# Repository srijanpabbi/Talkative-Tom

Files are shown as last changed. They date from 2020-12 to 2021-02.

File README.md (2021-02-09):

# Talkative-Tom
GOTO: https://srijanpabbi.in/projects/#topic_tt
Doc: https://srijanpabbi.blogspot.com/2020/01/talkative-tom.html
Audio storing &amp; playback device with pitch modification using MSP-430 TI-microcontroller / Atmega328P microcontroller, SPI Serial Flash for Storage &amp; class-D amplifier for speaker

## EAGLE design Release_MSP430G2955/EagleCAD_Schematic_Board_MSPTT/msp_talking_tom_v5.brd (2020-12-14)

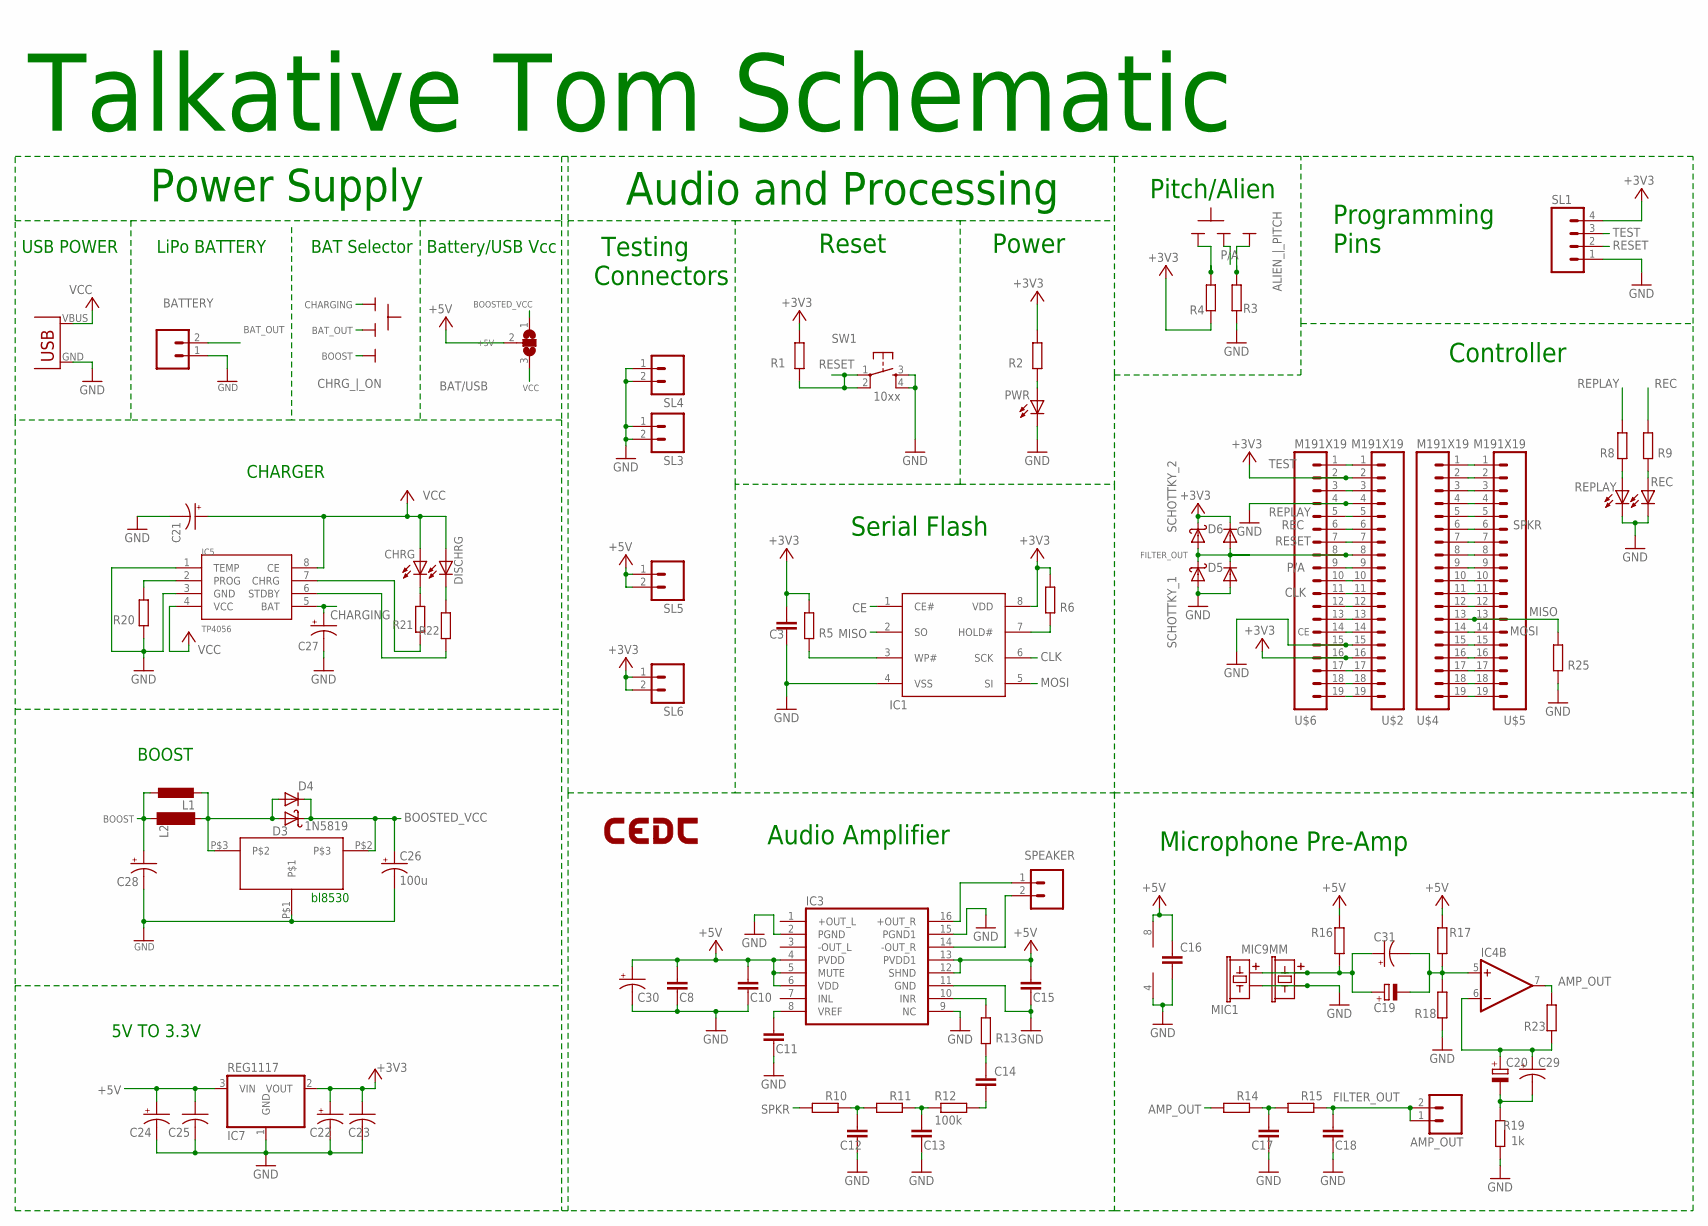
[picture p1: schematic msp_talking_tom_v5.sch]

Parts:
ALIEN_|_PITCH: SLIDESWITCH-BIG; BIGSWITCH
AMP_OUT: M02; 02P
BAT/USB: SJ2W; SJ_2
BATTERY: M02JST-PTH-2; 02P
C3, C12, C16, C17, C18, C23, C25: 0.1u; C0805
C8, C10, C15: 1uf; C1206
C11: 0.1uf; C1206
C13: 0.1uf; C0805
C14: 0.47uF; C0603
C19, C20: 10u; E2,5-5
C21, C22, C24, C27, C28, C29, C31: 10u; C/6032-28R
C26: 100u; C/6032-28R
C30: CAP_POL_10V; C/6032-28R
CHRG: LED3MM
CHRG_|_ON: SLIDESWITCH-BIG; BIGSWITCH
D3: 1N5819; DO41-10
D4, D5, D6: DIODE_DIODE-DO214AC; DIODE_DO214AC
DISCHRG: LED3MM
IC1: SST25VF040B_SPI_FLASH; SOIC08
IC3: PAM8403; SOP-16
IC4: LM358N; DIL08
IC5: TP4056; SOP-8
IC6: BL8530_5V
IC7: REG1117; SOT223
L1: L-EUL5650M; L5650M
L2: 47uH; MS85
LOGO2: LOGO-CEDTSILK-18MM; LOGO-CEDT-SILK-18MM
MIC1: MICMIC-4.5MM; MIC-4.5MM
MIC9MM: MIC9.7MM; MIC-9.7MM
PWR: LED3MM
R1, R3, R4, R5, R6, R13, R18, R25: 10k; 0204/7
R2, R8, R9, R19: 1k; 0204/7
R10, R11, R14, R15: 330; 0204/7
R12: 100k; 0204/7
R16: 4.7k; 0204/7
R17, R23: 20k; 0204/7
R20: R-EU_0204/7; 0204/7
R21, R22: 470; 0204/7
REC: LED3MM
REPLAY: LED3MM
SCHOTTKY_1, SCHOTTKY_2: 1N5819; DO41-10
SL1: M04; 04P
SL3, SL4, SL5, SL6: M02; 02P
SPEAKER: M02JST-PTH-VERT; 02P
SW1: 10xx; B3F-10XX
U$1: USB(POWER)
U$2, U$4, U$5, U$6: M191X19; 1X19

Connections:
+3V3: C3.1, C22.+, C23.1, D6.C, IC1.8 (VDD), IC7.2 (VOUT), R1.2, R2.2, R4.2, R5.1, R6.2, SCHOTTKY_2.C, SL1.4, SL6.1, SL6.2, U$2.2, U$2.16, U$6.2, U$6.16
+5V: BAT/USB.2, C8.1, C10.2, C15.2, C16.1, C24.+, C25.1, C30.+, IC3.4 (PVDD), IC3.5 (MUTE), IC3.6 (VDD), IC3.12 (SHND), IC3.13 (PVDD1), IC4.8 (V+), IC7.3 (VIN), R16.2, R17.2, SL5.1, SL5.2
AMP_OUT: IC4.7 (OUT), R14.1, R23.2
AVCC: U$4.16, U$5.16
BAT_OUT: BATTERY.2, CHRG_|_ON.2
BOOST: C28.+, CHRG_|_ON.3, L1.1, L2.1
BOOSTED_VCC: BAT/USB.1, C26.+, D3.C, D4.C, IC6.P$2
CE: IC1.1 (CE#), U$2.14, U$6.14
CHARGING: C27.+, CHRG_|_ON.1, IC5.5 (BAT)
CLK: IC1.6 (SCK), U$2.11, U$6.11
DVCC: U$4.2, U$5.2
FILTER_OUT: AMP_OUT.1, AMP_OUT.2, C18.1, D5.C, D6.A, R15.2, SCHOTTKY_1.C, SCHOTTKY_2.A, U$2.8, U$6.8
GND: BATTERY.1, C3.2, C8.2, C10.1, C11.2, C12.2, C13.2, C15.1, C16.2, C17.2, C18.2, C21.-, C22.-, C23.2, C24.-, C25.2, C26.-, C27.-, C28.-, C30.-, D5.A, IC1.4 (VSS), IC3.2 (PGND), IC3.9 (NC), IC3.11 (GND), IC3.15 (PGND1), IC4.4 (V-), IC5.1 (TEMP), IC5.3 (GND), IC6.P$1, IC7.1 (GND), MIC1.+ (2), MIC9MM.2, PWR.K (C), R3.2, R18.1, R19.1, R20.1, R25.1, REC.K (C), REPLAY.K (C), SCHOTTKY_1.A, SL1.1, SL3.1, SL3.2, SL4.1, SL4.2, SW1.3 (S), SW1.4 (S1), U$1.GND, U$2.4, U$2.15, U$6.4, U$6.15
MICIN1: C13.1, R11.2, R12.1
MISO: IC1.2 (SO), R25.2, U$4.13, U$5.13
MOSI: IC1.5 (SI), U$4.14, U$5.14
unnamed: U$2.3, U$6.3
unnamed: IC1.7 (HOLD#), R6.1
unnamed: IC1.3 (WP#), R5.2
unnamed: U$4.1, U$5.1
unnamed: U$4.15, U$5.15
unnamed: ALIEN_|_PITCH.3, R3.1
unnamed: U$4.4, U$5.4
unnamed: IC3.16 (+OUT_R), SPEAKER.1
unnamed: IC3.14 (-OUT_R), SPEAKER.2
unnamed: C14.2, R13.2
unnamed: IC3.10 (INR), R13.1
unnamed: C12.1, R10.2, R11.1
unnamed: PWR.A, R2.1
unnamed: C17.1, R14.2, R15.1
unnamed: IC5.2 (PROG), R20.2
unnamed: IC5.7 (CHRG), R21.1
unnamed: C14.1, R12.2
unnamed: R8.1, REPLAY.A
unnamed: C11.1, IC3.8 (VREF)
unnamed: ALIEN_|_PITCH.1, R4.1
unnamed: IC5.6 (STDBY), R22.1
unnamed: CHRG.K (C), R21.2
unnamed: DISCHRG.K (C), R22.2
unnamed: D3.A, D4.A, IC6.P$3, L1.2, L2.2
unnamed: C19.+, C31.+, MIC1.- (1), MIC9MM.1, R16.1
unnamed: C19.-, C31.-, IC4.5 (+IN), R17.1, R18.2
unnamed: C20.+, C29.+, IC4.6 (-IN), R23.1
unnamed: R9.2, REC.A
unnamed: U$2.19, U$6.19
unnamed: C20.-, C29.-, R19.2
unnamed: U$2.18, U$6.18
unnamed: U$2.17, U$6.17
unnamed: U$2.13, U$6.13
unnamed: U$2.12, U$6.12
unnamed: U$2.10, U$6.10
unnamed: U$4.3, U$5.3
unnamed: U$4.5, U$5.5
unnamed: U$4.7, U$5.7
unnamed: U$4.8, U$5.8
unnamed: U$4.9, U$5.9
unnamed: U$4.10, U$5.10
unnamed: U$4.11, U$5.11
unnamed: U$4.12, U$5.12
unnamed: U$4.17, U$5.17
unnamed: U$4.18, U$5.18
unnamed: U$4.19, U$5.19
P/A: ALIEN_|_PITCH.2, U$2.9, U$6.9
REC: R9.1, U$2.6, U$6.6
REPLAY: R8.2, U$2.5, U$6.5
RESET: R1.1, SL1.2, SW1.1, SW1.2 (P1), U$2.7, U$6.7
SPKR: R10.1, U$4.6, U$5.6
TEST: SL1.3, U$2.1, U$6.1
VCC: BAT/USB.3, C21.+, CHRG.A, DISCHRG.A, IC5.4 (VCC), IC5.8 (CE), U$1.VBUS (VCC)

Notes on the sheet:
Microphone Pre-Amp
Serial Flash
Reset
Testing Connectors
Controller
Audio Amplifier
Power
Programming Pins
Pitch/Alien
CHARGER
BOOST
5V TO 3.3V
bl8530
USB POWER
LiPo BATTERY
BAT Selector
Battery/USB Vcc
Power Supply
Audio and Processing
Talkative Tom Schematic

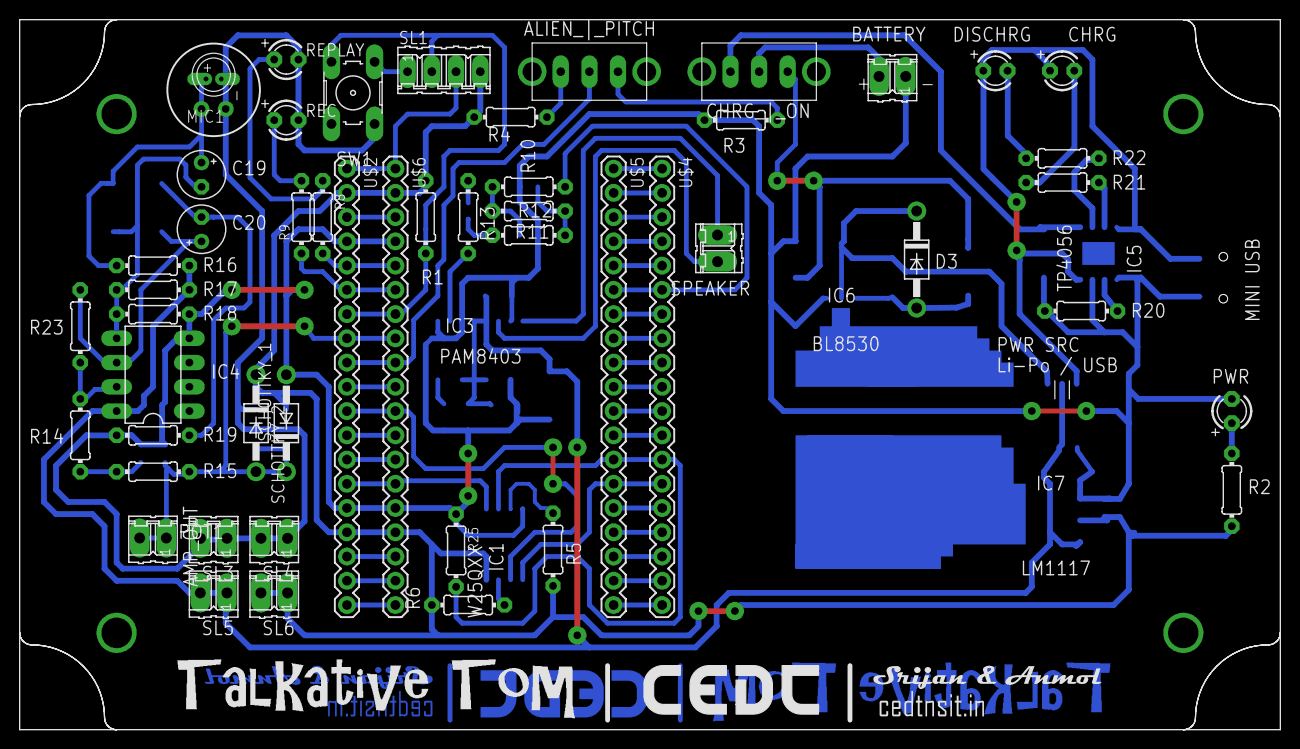
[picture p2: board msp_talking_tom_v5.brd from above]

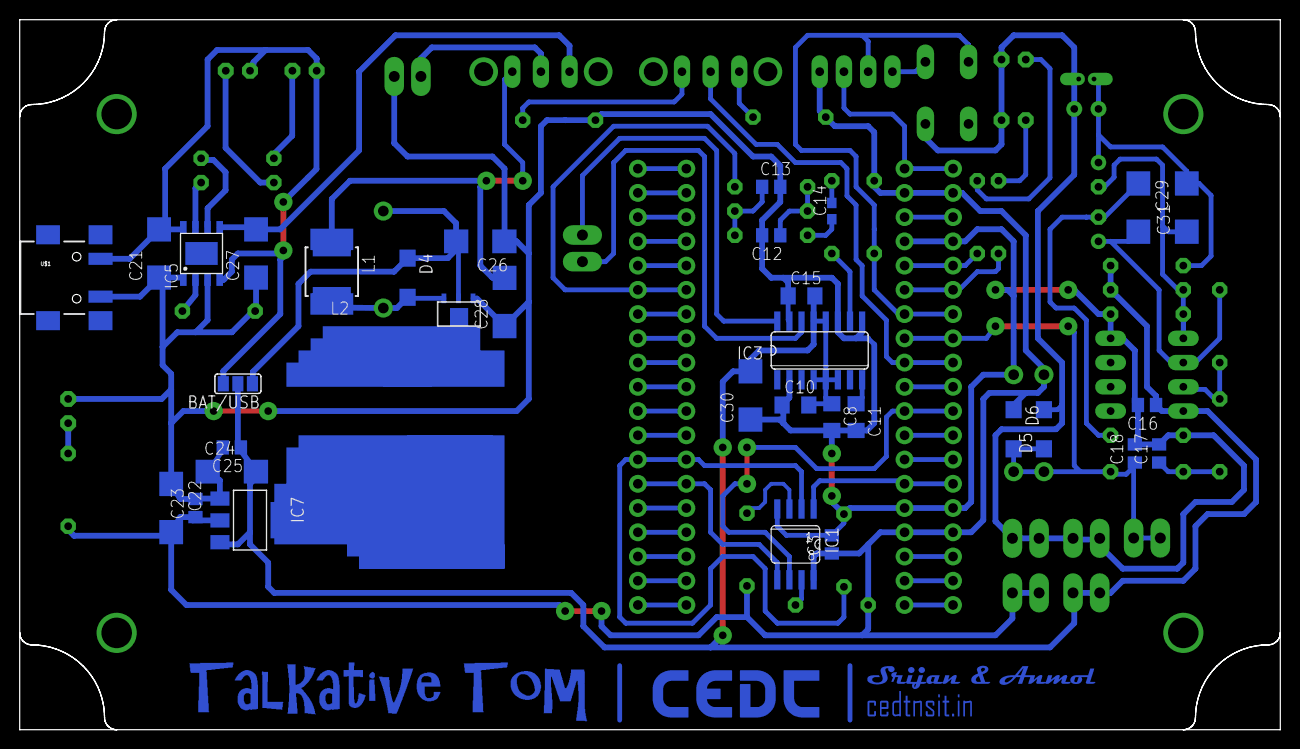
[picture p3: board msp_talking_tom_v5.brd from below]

Board: 2 copper layers, 132.1 x 74.4 mm, 86 parts (34 on the bottom side), 69 nets.

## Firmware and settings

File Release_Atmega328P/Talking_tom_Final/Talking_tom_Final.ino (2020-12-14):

#define WRITE_ENABLE       0x06
#define WRITE_DISABLE      0x04
#define CHIP_ERASE         0xc7
#define READ_STATUS_REG_1  0x05
#define READ_DATA          0x03
#define PAGE_PROGRAM       0x02
#define JEDEC_ID           0x9F
#define BLOCK_ERASE        0xD8

byte buf0[256];
byte buf1[256];
boolean enable_buf0 = true;
boolean enable_buf1 = false;
boolean write_pointer = true;
boolean read_pointer = true;
unsigned int bufByteCount = 0;
unsigned int buffByteCount = 0;
boolean flag = true;
int pagenumber = 0, recpage = 0;
uint8_t val = 0;
float current_ip = 0;
float previous_ip = 0;
//float lambda = 0.0001;
//float lambda = 0.005;
//float lambda = 0.01;
float lambda = 0.017;
//boolean startrec = false;
boolean mode;

inline float ewma() {
  current_ip = lambda * val * 1.0 + (1 - lambda) * previous_ip;
  previous_ip = current_ip;
  return previous_ip;
}

unsigned char transmit(unsigned char data) {
  SPDR = data;
  while (!(SPSR & (1 << SPIF)));
  return (SPDR);
}

void chip_erase(void) {
  PORTB |= 0X04;
  PORTB &= ~0X04;
  transmit(WRITE_ENABLE);
  PORTB |= 0X04;
  PORTB &= ~0X04;
  transmit(CHIP_ERASE);
  PORTB |= 0X04;
  not_busy();
}
void block_erase(word page_number) {
  PORTB |= 0X04;
  PORTB &= ~0X04;
  transmit(WRITE_ENABLE);
  PORTB |= 0X04;
  PORTB &= ~0X04;
  transmit(BLOCK_ERASE);
  transmit((page_number >>  8) & 0xFF);
  transmit((page_number >>  0) & 0xFF);
  transmit(0);
  PORTB |= 0X04;
  not_busy();
}
void _read_page(word page_number, byte *page_buffer) {
  PORTB |= 0X04;
  PORTB &= ~0X04;
  transmit(READ_DATA);
  transmit((page_number >> 8) & 0xFF);
  transmit((page_number >> 0) & 0xFF);
  transmit(0);
  for (int i = 0; i < 256; ++i) {
    page_buffer[i] = transmit(0);
  }
  PORTB |= 0X04;
  not_busy();
}

void _write_page(word page_number, byte *page_buffer) {
  PORTB |= 0X04;
  PORTB &= ~0X04;
  transmit(WRITE_ENABLE);
  PORTB |= 0X04;
  PORTB &= ~0X04;
  transmit(PAGE_PROGRAM);
  transmit((page_number >>  8) & 0xFF);
  transmit((page_number >>  0) & 0xFF);
  transmit(0);
  for (int i = 0; i < 256; ++i) {
    transmit(page_buffer[i]);
  }
  PORTB |= 0X04;
  not_busy();
}

//void _erase_page(word page_number ) {
//  PORTB |= 0X04;
//  PORTB &= ~0X04;
//  transmit(WRITE_ENABLE);
//  PORTB |= 0X04;
//  PORTB &= ~0X04;
//  transmit(SECTOR_ERASE);
//  transmit((page_number >>  8) & 0xFF);
//  transmit((page_number >>  0) & 0xFF);
//  transmit(0);
//  PORTB |= 0X04;
//  not_busy();
//}
void not_busy(void) {
  PORTB |= 0X04;
  PORTB &= ~0X04;
  transmit(READ_STATUS_REG_1);
  while (transmit(0) & 1) {};
  PORTB |= 0X04;
}

void adc_set_update() {
  pagenumber = 0;
  OCR0A = 128;// set PWM for 50% duty cycle
  ADCSRA |= 1 << ADPS2;    // makes ADPS2 AS 0
  ADCSRA &= ~ 1 << ADPS1;
  ADCSRA &= ~ 1 << ADPS0;
}

void setup() {
  DDRD &= ~ (1 << DDD7);
  //  mode = mode = (PIND >> 7);

  //  if (mode) {
  //    ADCSRA |= 1 << ADPS2;    // makes ADPS2 AS 0
  //    ADCSRA &= ~1 << ADPS1;
  //    ADCSRA &= ~ 1 << ADPS0;
  //  } else {
  //    ADCSRA |= 1 << ADPS2;
  //    ADCSRA &= ~ 1 << ADPS1;
  //    ADCSRA |= 1 << ADPS0;
  //  }

  ADMUX |= 1 << ADLAR;
  ADMUX |= 1 << MUX1;
  ADMUX |= 1 << MUX0;
  ADCSRA |= 1 << ADIE;
  ADCSRA |= 1 << ADEN;
  DDRB |= 0X2C;
  DDRB |= 0x03;
  PORTB |= 0x00;
  SPCR |= 1 << MSTR ;
  SPCR |= 1 << SPE;
  DDRD = 0;
  DDRD |= (1 << DDD6);
  OCR0A = 0;
  TCCR0A |= (1 << COM0A1);
  TCCR0A |= (1 << WGM01) | (1 << WGM00);
  TCCR0B |= (1 << CS00);
  TCCR0B &= ~(1 << CS01);
  TCCR0B &= ~(1 << CS02);

  //profiling
  DDRC |= 0x01;
  PORTC |= 0x00;
  
  sei();
  ADCSRA |= 1 << ADSC;
}

void loop() {
  OCR0A = 0;
  block_erase(0);
  block_erase(256);
  //  block_erase(512);
  //  block_erase(768);
  //  block_erase(1024);

  mode = (PIND >> 7);
  //  mode = true;
  if (mode) {
    ADCSRA |= 1 << ADPS2;    // makes ADPS2 AS 0
    ADCSRA &= ~ 1 << ADPS1;
    ADCSRA &= ~ 1 << ADPS0;
  } else {
    ADCSRA |= 1 << ADPS2;
    ADCSRA &= ~ 1 << ADPS1;
    ADCSRA |= 1 << ADPS0;
  }

  OCR0A = 0;
  pagenumber = 0;
  recpage = 0;
  flag = true;
  PORTB &= ~ (0x03);

  sei();
  ADCSRA |= 1 << ADSC;
  while (ewma() < 28) {
    val = abs(ADCH - 132);
  }
  while (pagenumber < 256 && ewma() > 1.3) {//1.1,1.2,1.3,....
    PORTB |= 0x01;
    if (enable_buf0 && !write_pointer) {
      pagenumber++;
      _write_page(pagenumber, buf0);
      enable_buf0 = false;
    }
    if (enable_buf1 && write_pointer) {
      pagenumber++;
      _write_page(pagenumber, buf1);
      enable_buf1 = false;
    }
  }
  recpage = pagenumber;
  cli();

  //  if (!mode) {
  //    adc_set_update();
  //  } else {
  //    ADCSRA |= 1 << ADPS2;    // makes ADPS2 AS 0
  //    ADCSRA &= ~1 << ADPS1;
  //    ADCSRA &= ~ 1 << ADPS0;
  //  }

  adc_set_update();

  pagenumber = 0;
  flag = false;
  sei();
  ADCSRA |= 1 << ADSC;
  while (pagenumber < recpage) {
    PORTB |= 0x02;
    if (enable_buf0 && !read_pointer) {
      pagenumber++;
      _read_page(pagenumber, buf0);
      enable_buf0 = false;
    }
    if (enable_buf1 && read_pointer) {
      pagenumber++;
      _read_page(pagenumber, buf1);
      enable_buf1 = false;
    }
  }
  cli();
  val = 0;
  PORTB &= ~ (0x03);
  PORTD = 0x00;
  //  DDRD = 0xff;
  //  ADCSRA |= 1 << ADPS2;
  //  ADCSRA &= ~ 1 << ADPS1;
  //  ADCSRA |= 1 << ADPS0;

  mode = (PIND >> 7);
  if (mode) {
    ADCSRA |= 1 << ADPS2;    // makes ADPS2 AS 0
    ADCSRA &= ~1 << ADPS1;
    ADCSRA &= ~ 1 << ADPS0;
  } else {
    ADCSRA |= 1 << ADPS2;
    ADCSRA &= ~ 1 << ADPS1;
    ADCSRA |= 1 << ADPS0;
  }

  ADMUX |= 1 << ADLAR;
  ADMUX |= 1 << MUX1;
  ADMUX |= 1 << MUX0;
  ADCSRA |= 1 << ADIE;
  ADCSRA |= 1 << ADEN;
  OCR0A = 0;
}
ISR(ADC_vect) {
  //profiling
//  PORTC |= 0x01;
//  PORTC &=~(0x01);
  
  if (flag) {
    OCR0A = 0;
    bufByteCount++;
    if (bufByteCount == 256) {
      bufByteCount = 0;
      enable_buf0 = true;
      enable_buf1 = true;
      write_pointer = !write_pointer;
      val = abs( ADCH - 132);
    }
    if (enable_buf0 && write_pointer) {
      buf0[bufByteCount] = ADCH;
    }
    if (enable_buf1 && !write_pointer) {
      buf1[bufByteCount] = ADCH;
    }

    ADCSRA |= 1 << ADSC;
    return;
  }

  if (!flag && mode) {
    ADCSRA |= 1 << ADSC;
    buffByteCount++;
    if (buffByteCount == 256) {
      buffByteCount = 0;
      enable_buf0 = true;
      enable_buf1 = true;
      read_pointer = !read_pointer;
    }
    if (enable_buf0 && read_pointer) {
      OCR0A = buf0[buffByteCount];
    }
    if (enable_buf1 && !read_pointer) {
      OCR0A = buf1[buffByteCount];
    }

    //    ADCSRA |= 1 << ADSC;u
    return;
  }

  if (!flag && !mode) {
    buffByteCount++;
    if (buffByteCount == 256) {
      buffByteCount = 0;
      enable_buf0 = true;
      enable_buf1 = true;
      read_pointer = !read_pointer;
    }
    if (enable_buf0 && read_pointer) {
      OCR0A = buf0[buffByteCount];
      delayMicroseconds(10);
    }
    if (enable_buf1 && !read_pointer) {
      OCR0A = buf1[buffByteCount];
      delayMicroseconds(10);
    }

    ADCSRA |= 1 << ADSC;
    return;
  }
}

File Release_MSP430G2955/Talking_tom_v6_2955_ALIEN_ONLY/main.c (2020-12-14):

//FINAL 1 ONLY PITCH CHANGE

#include <msp430.h>
#include<stdbool.h>
#include<inttypes.h>

#define WRITE_ENABLE       0x06
#define WRITE_DISABLE      0x04
#define CHIP_ERASE         0xc7
#define READ_STATUS_REG_1  0x05
#define READ_DATA          0x03
#define PAGE_PROGRAM       0x02
#define JEDEC_ID           0x9F
#define BLOCK_ERASE        0xD8

#define abs(x) ((x>0)?(x):(-x))
//volatile int v1;
volatile unsigned char buf0[256];
volatile unsigned char buf1[256];
volatile unsigned int i = 0;
_Bool enable_buf0 = 1;
_Bool enable_buf1 = 0;
_Bool write_pointer = 1;
_Bool read_pointer = 1;
_Bool flag = 1;
//unsigned int *enable_buf0 = (unsigned int*)0x0800;
//unsigned int *enable_buf1 = (unsigned int*)0x0801;
//unsigned int *write_pointer = (unsigned int*)0x0802;
//unsigned int *read_pointer = (unsigned int*)0x0803;
//unsigned int *flag = (unsigned int*)0x0804;
//*enable_buf0 = 0x0001;
//*enable_buf1 = 0x0000;
//*write_pointer = 0x0001;
//*read_pointer = 0x0001;
//*flag = 1;

volatile unsigned int bufByteCount = 0;
volatile unsigned int buffByteCount = 0;
volatile unsigned long pagenumber = 0, recpage = 0;

//When the USCI module is enabled by clearing the UCSWRST bit it is ready to receive and transmit.
//A transmit or receive operation is indicated by UCBUSY = 1
//UCMODEx 10
//In master mode, writing to UCxTXBUF activates the bit clock generator and the data will begin to transmit
//The UCA0TXIFG interrupt flag is set by the transmitter to indicate that UCxTXBUF is ready to accept another character.
//The UCA0RXIFG interrupt flag is set each time a character is received and loaded into UCxRXBUF.
//Interrupts are handled by setting UCxRXIE and GIE
//UCB0TXIFG is set when UCB0TXBUF is empty and transmission is complete
//UCB0RXIFG is set when UCB0RXBUF is empty and recieving  is complete
//Default UCCKPH, UCCKPL, UC7BIT
//To Set in UCAxCTL0 : UCMSB(1), UCMST(1), UCMODEx(10), UCSYNC(1)
//TO Set in UCAxCTL1 : UCSSELx(10 or 11), UCSWRST(0)

uint8_t val = 0;
uint8_t temp = 0;
float current_ip = 0;
float previous_ip = 0;
float lambda = 0.017;
_Bool mode;

inline float ewma()
{
    current_ip = lambda * val * 1.0 + (1 - lambda) * previous_ip;
    previous_ip = current_ip;
    return previous_ip;
}

unsigned char transmit(unsigned char data)
{
    while (!(IFG2 & UCA0TXIFG))
        ;
    UCA0TXBUF = data;
    while (!(IFG2 & UCA0TXIFG))
        ;
    while (!(IFG2 & UCA0RXIFG))
        ; // As soon as the transmit is complete the SPIF bit is set in the SPSR register of the spi module. The while condition is turned to 0 as soon as this happens
    return (UCA0RXBUF);
}
void unbusy(void)
{
    P3OUT |= BIT3;
    P3OUT &= ~BIT3;
    transmit(READ_STATUS_REG_1);
    while (transmit(0x00) != 0x00)
    {
    };
    while (!(IFG2 & UCA0TXIFG))
        ;
    P3OUT |= BIT3;
}

void block_erase(unsigned long page_number)
{
    P3OUT |= BIT3;
    P3OUT &= ~BIT3;
    transmit(WRITE_ENABLE);
    while (!(IFG2 & UCA0TXIFG))
        ;
    P3OUT |= BIT3;
    P3OUT &= ~BIT3;
    transmit(BLOCK_ERASE);
    transmit((page_number >> 8) & 0xFF);
    transmit((page_number >> 0) & 0xFF);
    transmit(0);
    while (!(IFG2 & UCA0TXIFG))
        ;
    P3OUT |= BIT3;
    unbusy();
}
void _read_page(unsigned long page_number, volatile unsigned char page_buffer[])
{
    P3OUT |= BIT3;
    P3OUT &= ~BIT3;
    transmit(READ_DATA);
    transmit((page_number >> 8) & 0xFF);
    transmit((page_number >> 0) & 0xFF);
    transmit(0);
    i = 0;
    for (i = 0; i < 256; ++i)
    {
        page_buffer[i] = transmit(0);
    }
    while (!(IFG2 & UCA0TXIFG))
        ;
    P3OUT |= BIT3;
    unbusy();
}

void _write_page(unsigned long page_number,
                 volatile unsigned char page_buffer[])
{
    P3OUT |= BIT3;
    P3OUT &= ~BIT3;
    transmit(WRITE_ENABLE);
    while (!(IFG2 & UCA0TXIFG))
        ;
    P3OUT |= BIT3;
    P3OUT &= ~BIT3;
    transmit(PAGE_PROGRAM);
    transmit((page_number >> 8) & 0xFF);
    transmit((page_number >> 0) & 0xFF);
    transmit(0);
    i = 0;
    for (i = 0; i < 256; ++i)
    {
        transmit(page_buffer[i]);
    }
    while (!(IFG2 & UCA0TXIFG))
        ;
    P3OUT |= BIT3;
    unbusy();
}

int main(void)
{
    WDTCTL = WDTPW | WDTHOLD;   // Stop watchdog timer

    BCSCTL1 = CALBC1_8MHZ;              // Set DCO to 8MHz
    DCOCTL = CALDCO_8MHZ;

//    BCSCTL1 |= BIT3 + BIT2 + BIT1 + BIT0;
//    DCOCTL |= BIT7 + BIT6 + BIT5;

//    P2DIR |= BIT1;                         // P2.1-> Output
//    P2SEL |= BIT1;                         // P2.1 -> Select Timer Output
    P1DIR |= BIT2;        //P1.2 as TA0.1
    P1SEL |= BIT2;
    TACCR0 = 255;                             // Set Timer0 PWM Period
    TACCTL1 = OUTMOD_7; // Set TA0.1 Waveform Mode - Clear on Compare, Set on Overflow
    TACCR1 = 0;                               // Set TA0.1 PWM duty cycle
    TACTL = TASSEL_2 + MC_1;           // Timer Clock -> SMCLK, Mode -> Up Count

    P3DIR |= BIT3;                                     // Set 3.3 as output(CE)
    P3OUT |= BIT3;
    P2SEL &=~(BIT6+BIT7);
     P2DIR |=BIT6+BIT7;
//     P2OUT &= ~(BIT6 + BIT7);
//    __delay_cycles(10000);
P2OUT |= BIT6+BIT7;
//        __delay_cycles(10000);
P2OUT &=~(BIT6+BIT7);
    P3SEL |= BIT0 + BIT4 + BIT5;      //P3.0 -> CLK , P3.4 -> SIMO, P3.5 -> SOMI

    UCA0CTL1 |= UCSWRST;                            // Hold USCI in reset state
    UCA0CTL0 |= UCCKPH + UCMST + UCSYNC + UCMSB; // 3-pin, 8-bit, SPI Master
    UCA0CTL1 |= UCSSEL_2;                           // Clock -> SMCLK
    UCA0BR0 = 0x02;                                 // SPI CLK -> SMCLK/2
    UCA0BR1 = 0;
    UCA0MCTL = 0;
    UCA0CTL1 &= ~UCSWRST;

    ADC10CTL0 &= ~ENC; //disable conversion so that we could change the values of the index bits locked
    ADC10CTL1 |= INCH_0 + ADC10DIV_7 + ADC10SSEL_3 + CONSEQ_0;
    ADC10AE0 |= BIT0;
    ADC10CTL0 |= ADC10SHT_3 + ADC10ON + ADC10IE;
//    __enable_interrupt();
//    ADC10CTL0 |= ENC + ADC10SC;

    while (1)
    {
        P2OUT &= ~(BIT6 + BIT7);
        i = 0;
        for (i = 0; i < 1000; i = i + 256)
        {
            block_erase(i);
        }
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

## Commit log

2020-12-14 Add files via upload
    cad files
    [TalkingTom_FINAL9.brd, TalkingTom_FINAL9.sch]
2020-12-14 Add files via upload
    caf files atmega
    [TalkingTom_FINAL9.brd, TalkingTom_FINAL9.sch]

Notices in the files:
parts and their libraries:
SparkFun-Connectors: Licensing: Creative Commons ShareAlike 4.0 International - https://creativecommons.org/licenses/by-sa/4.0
